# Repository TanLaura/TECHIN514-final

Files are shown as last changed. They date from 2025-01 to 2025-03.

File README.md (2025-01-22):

# TECHIN514-final

## Daily Habit Tracker
The device tracks the number of task completed (chips in the collector/sensing device) and show the progress with the stepper gauge needle. The LED light can be on the scale of red to green based on percentage of completion. It relies on the load cell and amplifier to calculate the number of chips of completed tasks and completion rate based on the set goal of the day. The stepper motor gauge and LED will display the progress. The display device also have the option to set the goals.

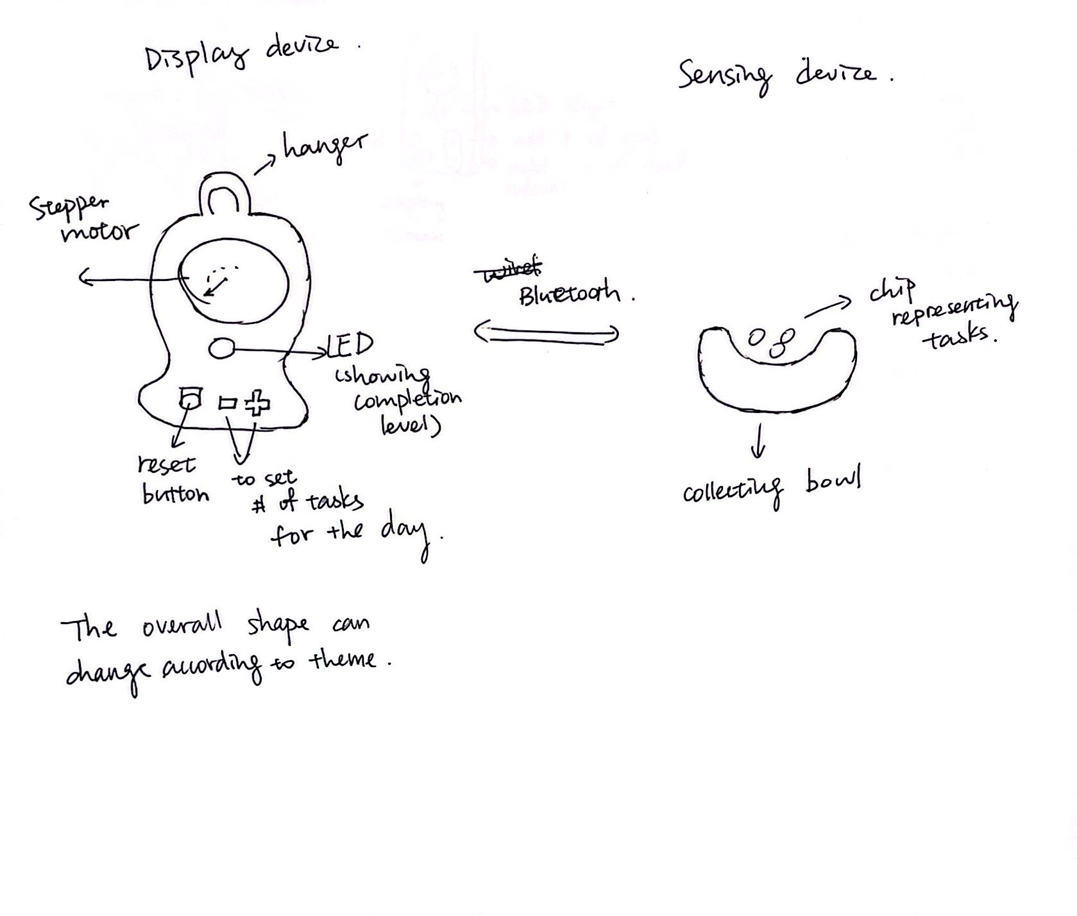
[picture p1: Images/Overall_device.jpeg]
Overview Graph


## Sensor device
The sensor device looks like a bowl overall. There is a load cell and amplifier that read the weight and translate it to voltage. It calculates the percentage of task completion and send the data to display device for further information display.
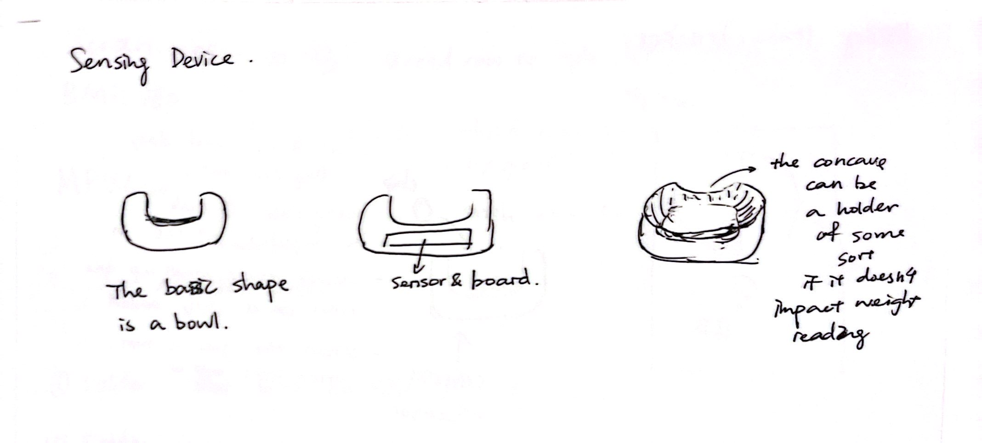
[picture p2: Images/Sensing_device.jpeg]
Sensing Device


## Display Device
The outer shape can be varied based on the final PCB shape and size. The diplay has a stepper motor gauge and LED light both shows the completion rate of the task in different forms. It has a reset button and button to adjust the goal of the day.
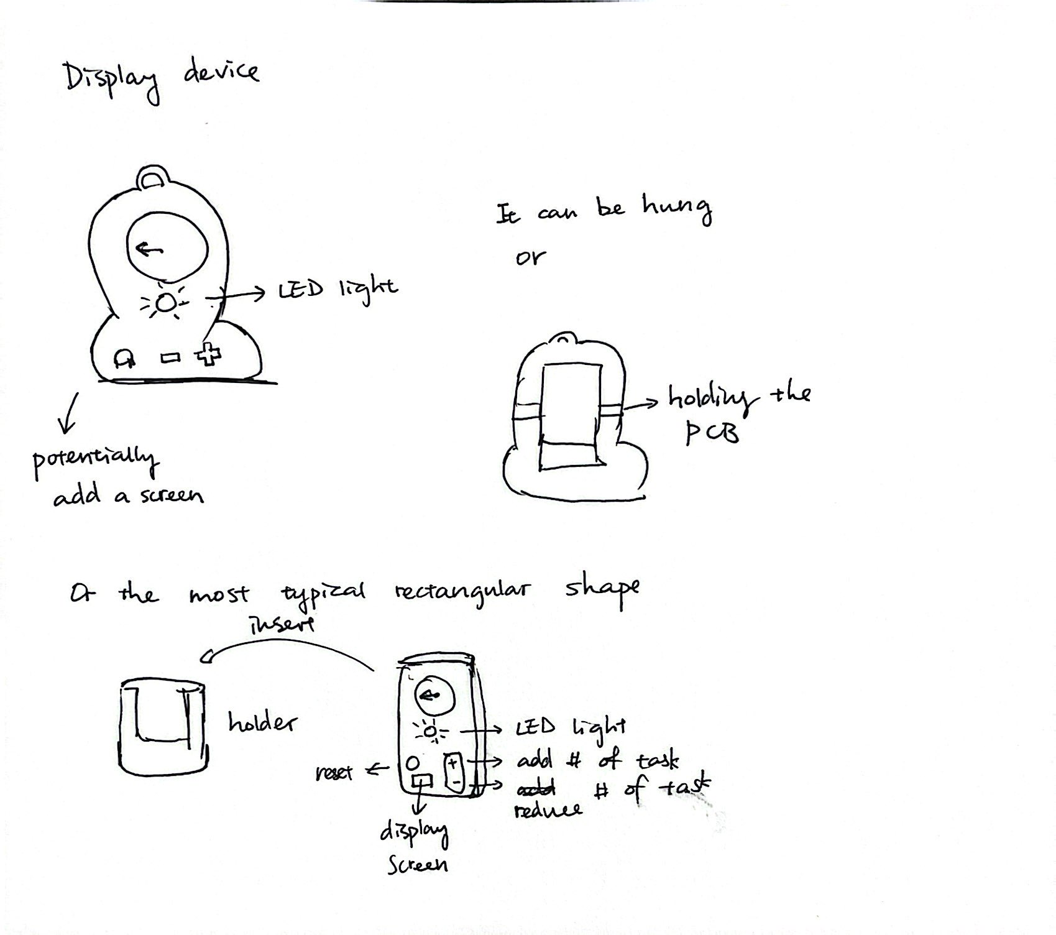
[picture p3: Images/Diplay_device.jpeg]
Display Device


## Device Communicatioin 

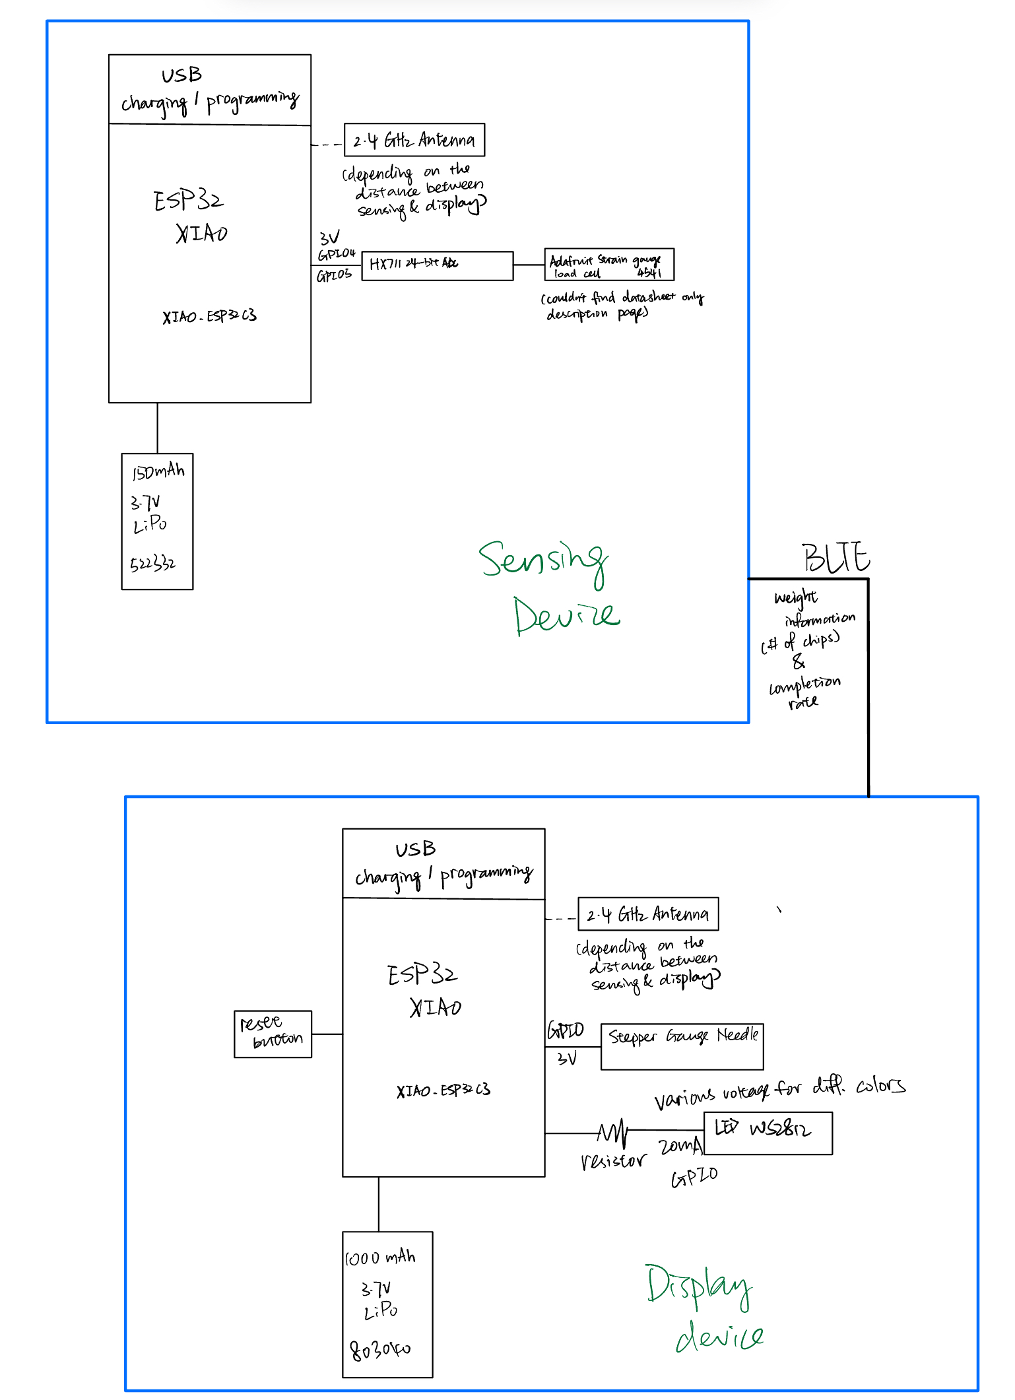
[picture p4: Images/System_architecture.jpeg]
System architecture


### Component Lists
- [Seeduino ESP32C3](Datasheets/Seeduino ESP32c3.pdf)
- [Load cell](https://www.adafruit.com/product/4541#description): The load cell seems to only have a webpage with product details instead of a datasheet.
- [HX711](Datasheets/adafruit-hx711-24-bit-adc.pdf)
- [Stepper Motor Gauage](Datasheets/stepd-01-data-sheet-1143075.pdf)
- [LED WS2812](Datasheets/WS2812.pdf)

### Potential Component to Add after Discussion 
- A small display screen
- The reset button (and its form)
- A charging circuit?
- Sleep mode?

These are all questions I want to go over with the instruction team to finalize the component list and structure.

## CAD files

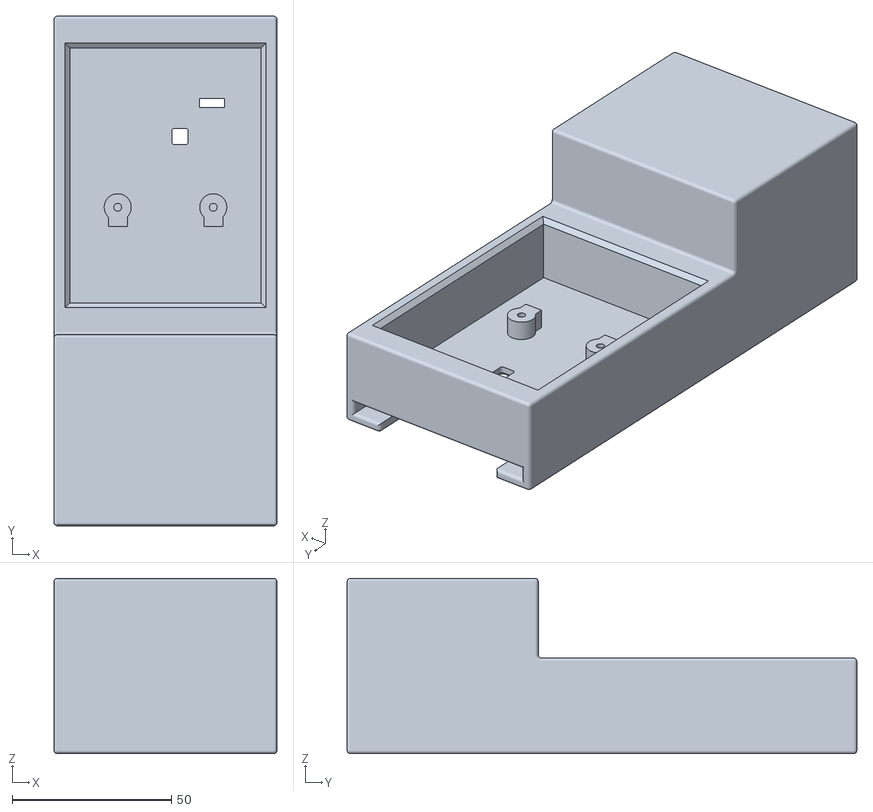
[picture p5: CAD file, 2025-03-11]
Enclosure/Sensor_Enclosure/Sensor_main.stl
70.0 x 160.0 x 55.0

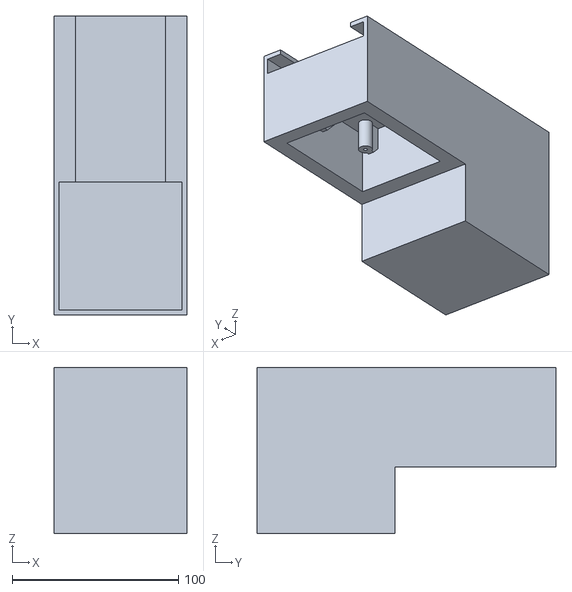
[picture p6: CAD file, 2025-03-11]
Enclosure/Sensor_Enclosure/Main body.stl
80.0 x 180.0 x 100.0

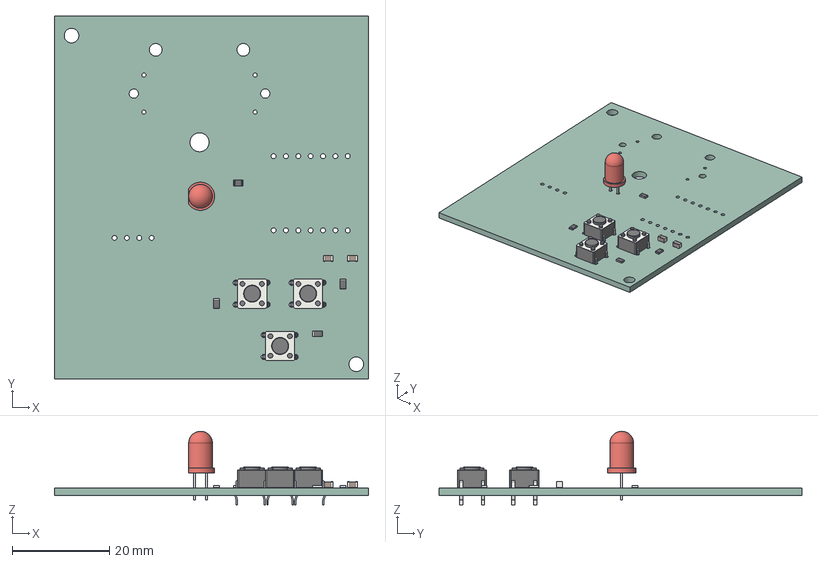
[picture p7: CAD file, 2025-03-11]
Enclosure/Display_Enclosure/514_final_display_pcb.step
64.5 x 74.5 x 15.1 mm
LED_D5.0mm
R_0805_2012Metric x 4
SW_PUSH_6mm x 3
C_0805_2012Metric x 2
514_final_display_pcb_PCB

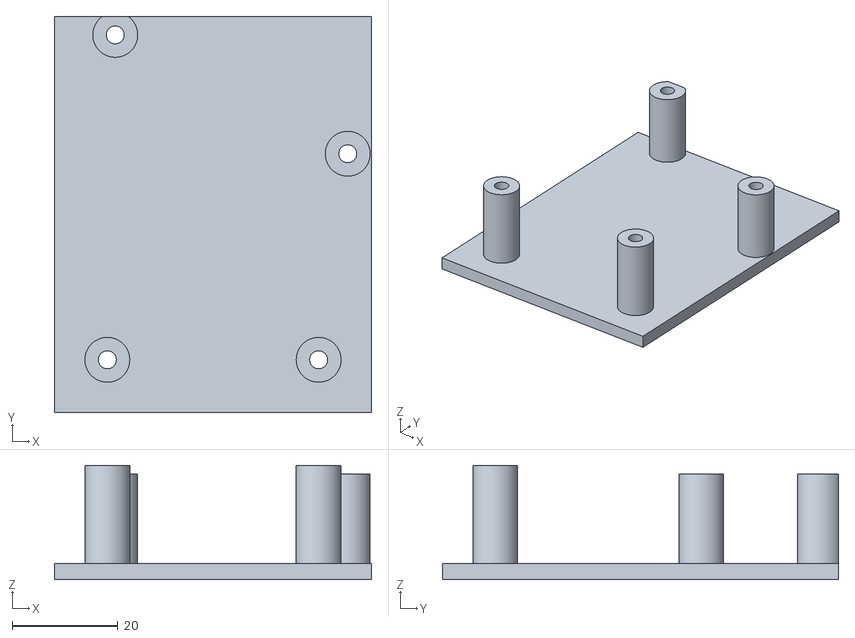
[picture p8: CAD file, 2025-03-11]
Enclosure/Sensor_Enclosure/Lid.stl
60.0 x 75.0 x 21.6

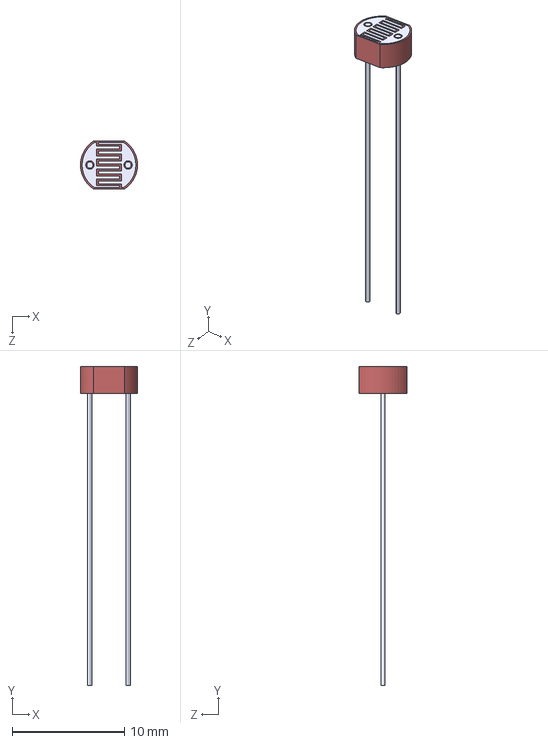
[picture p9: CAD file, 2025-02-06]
kiCAD resources/CDS_PDV_P8103/PDV-P8103.step
5.07 x 28.4 x 4.29 mm

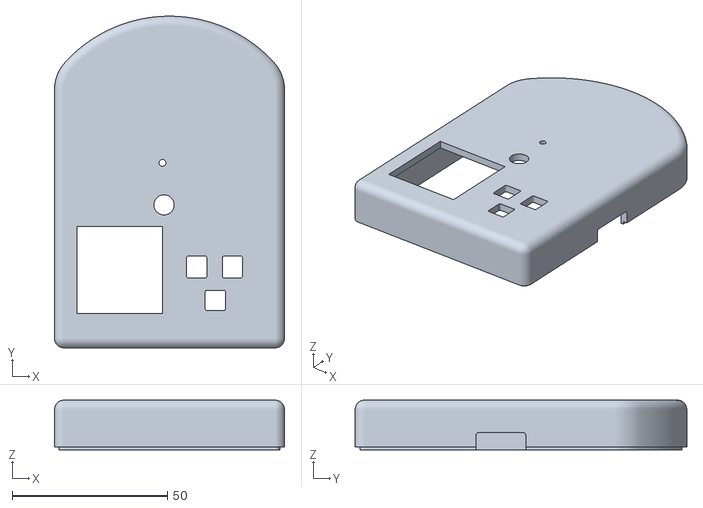
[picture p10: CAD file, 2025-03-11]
Enclosure/Display_Enclosure/Display_lid.stl
74.0 x 106.7 x 16.0

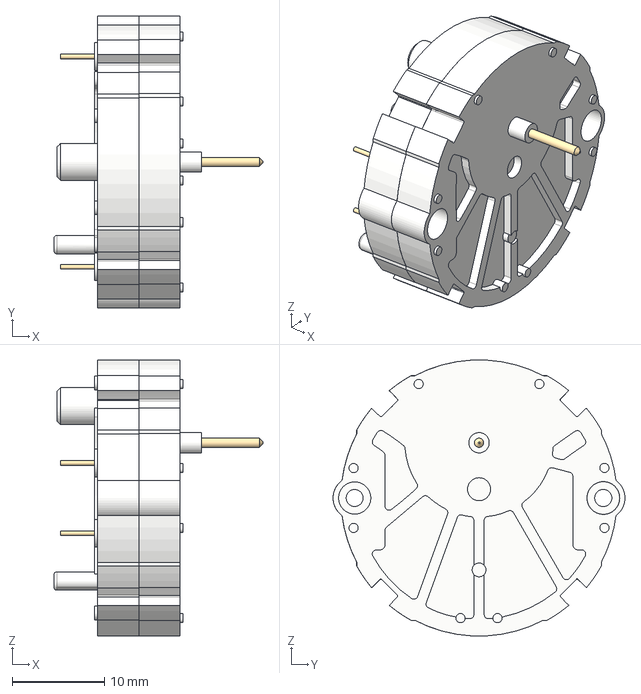
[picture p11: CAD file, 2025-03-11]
Enclosure/Display_Enclosure/X27-168-Stepper v5 (1).step
22.7 x 31.7 x 30.0 mm

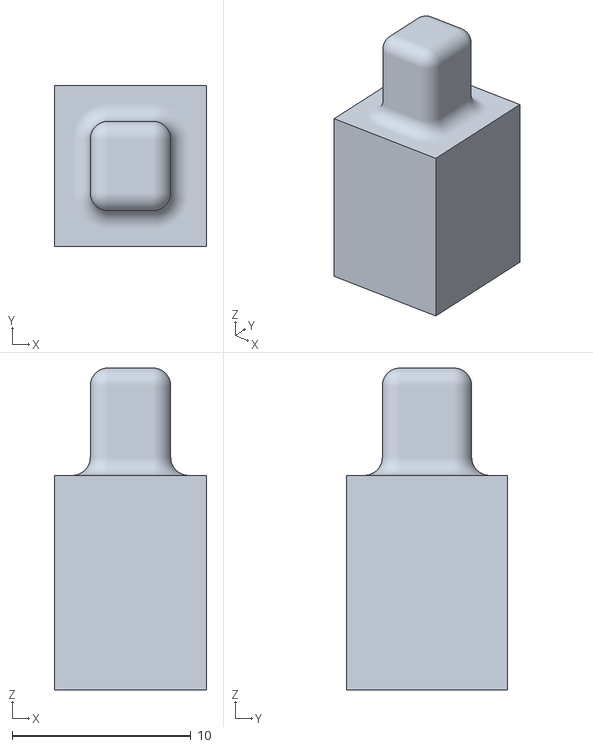
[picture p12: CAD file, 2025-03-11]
Enclosure/Display_Enclosure/button 2.stl
8.50 x 9.00 x 18.0

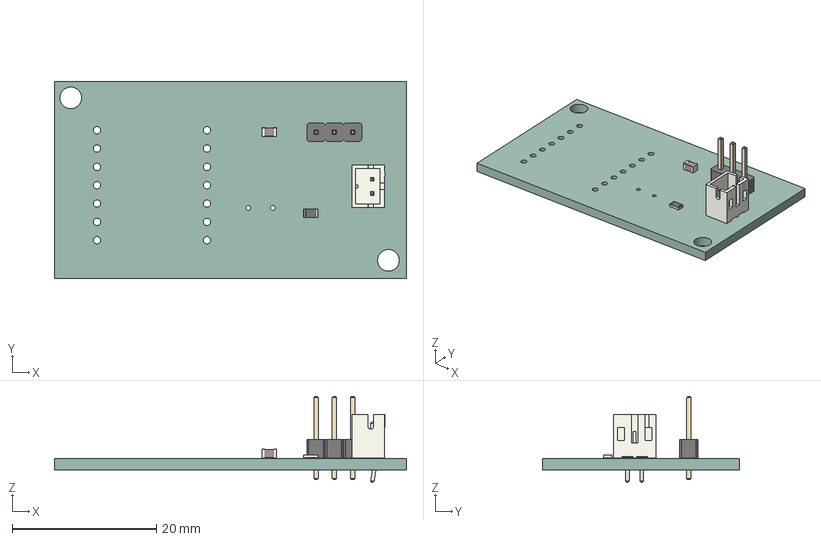
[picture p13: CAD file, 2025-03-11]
Enclosure/Sensor_Enclosure/514_final_sensor_pcb.step
48.8 x 27.2 x 11.9 mm
JST_B2B_PH_K
R_0805_2012Metric
C_0805_2012Metric
PinHeader_1x03_P254mm_Vertical
514_final_sensor_pcb_PCB

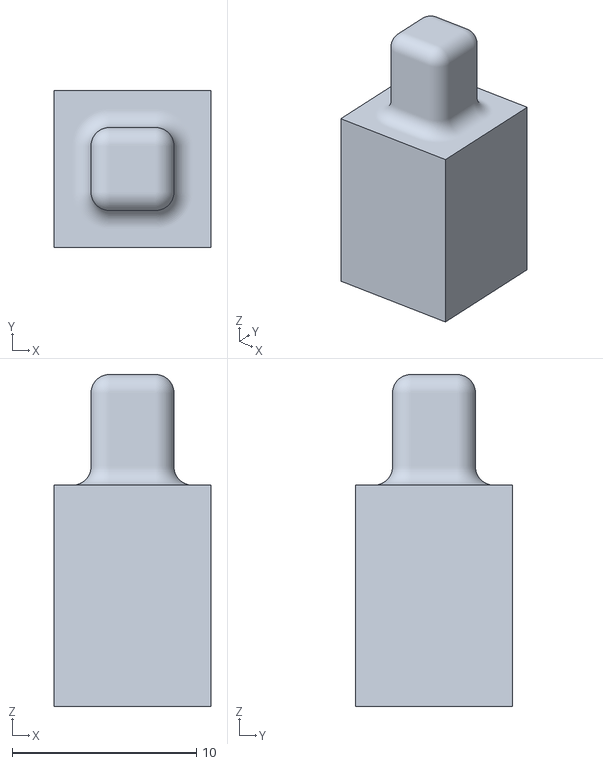
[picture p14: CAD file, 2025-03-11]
Enclosure/Display_Enclosure/button 3.stl
8.50 x 8.50 x 18.0

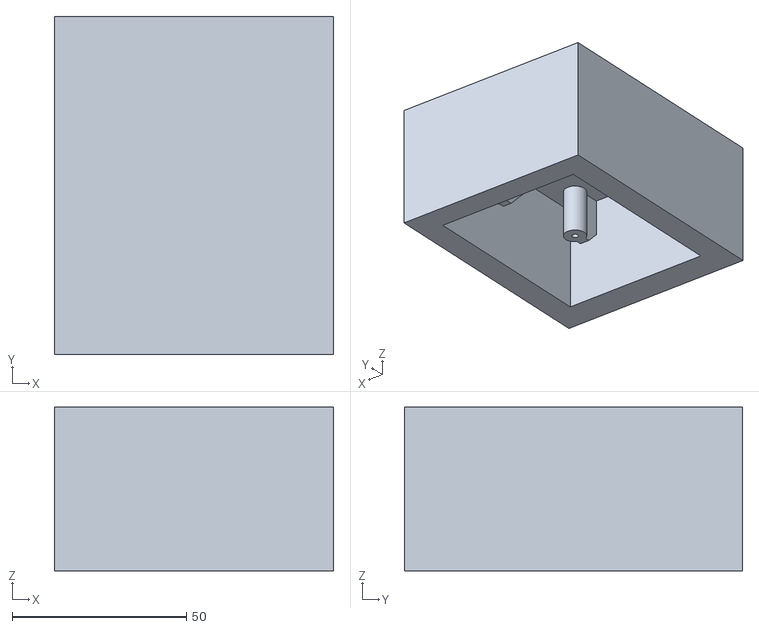
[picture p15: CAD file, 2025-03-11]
Enclosure/Sensor_Enclosure/PCB body.stl
80.0 x 97.0 x 47.0

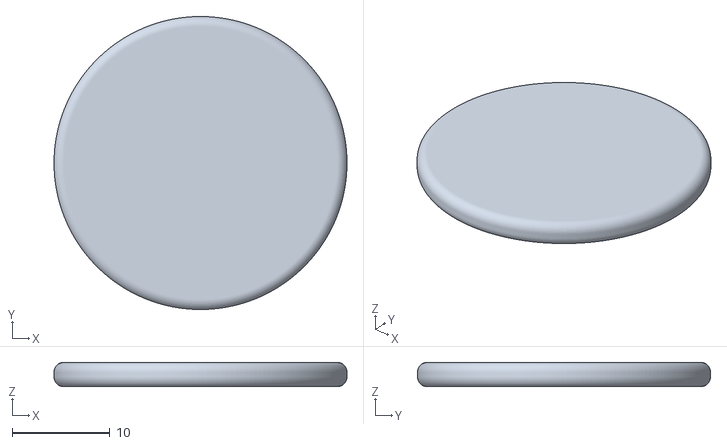
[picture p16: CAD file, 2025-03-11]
Enclosure/Display_Enclosure/Token.stl
30.0 x 30.0 x 2.50

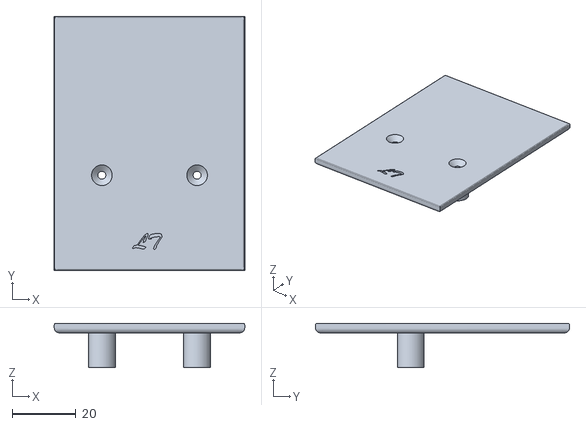
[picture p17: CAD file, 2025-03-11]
Enclosure/Sensor_Enclosure/sensor_lid.stl
60.0 x 80.0 x 14.0

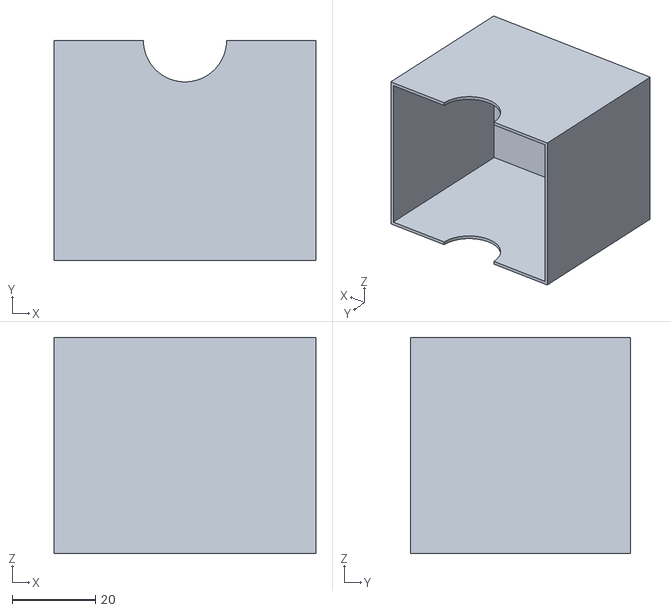
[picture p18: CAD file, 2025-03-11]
Enclosure/Sensor_Enclosure/sensor_drawer.stl
63.0 x 53.0 x 52.0

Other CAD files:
Enclosure/Display_Enclosure/Button.stl
Enclosure/Display_Enclosure/display_bottom.stl
Enclosure/Sensor_Enclosure/Sensor_enclosure v5.step
Enclosure/Sensor_Enclosure/Sensor_enclosure v5.f3d

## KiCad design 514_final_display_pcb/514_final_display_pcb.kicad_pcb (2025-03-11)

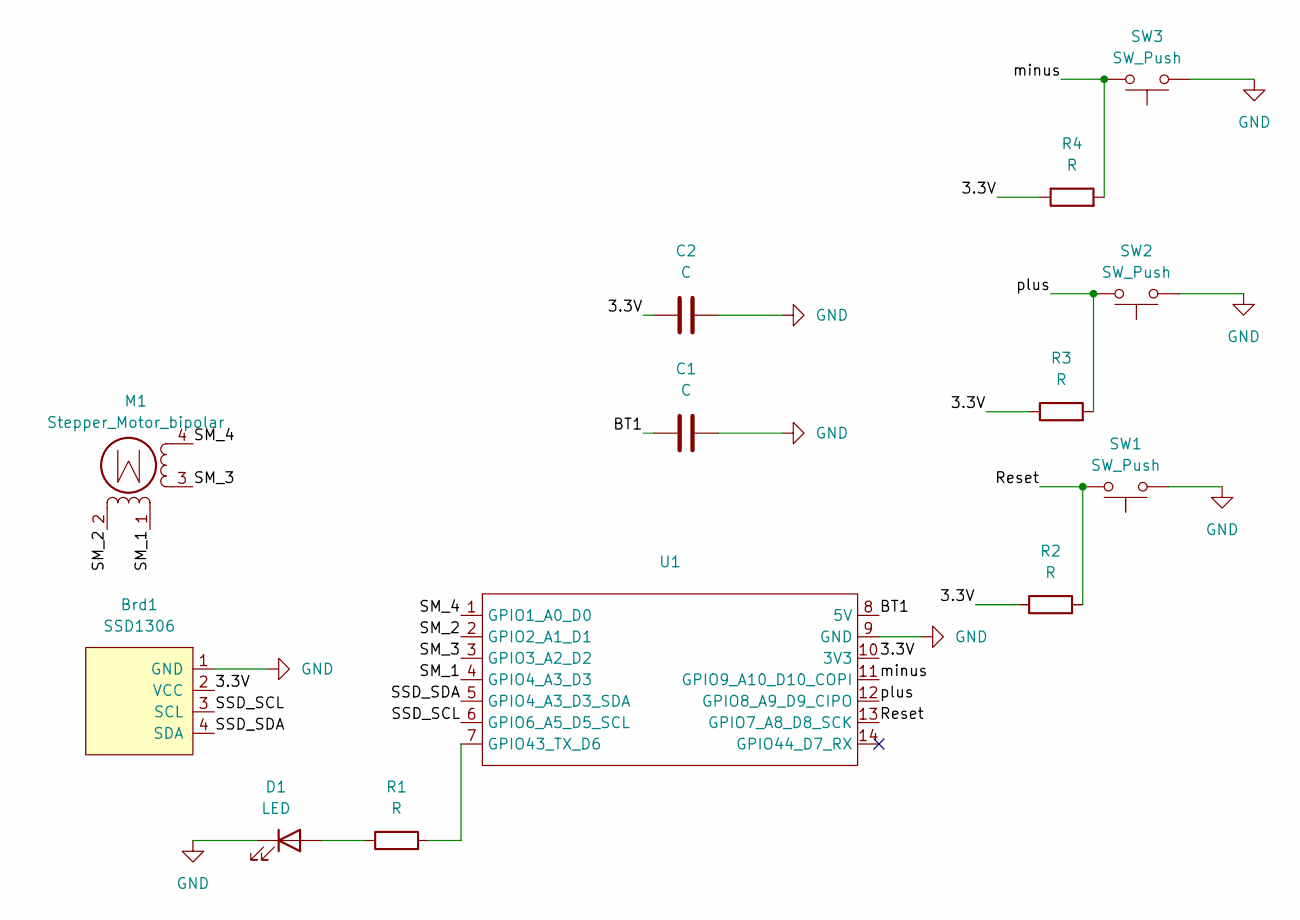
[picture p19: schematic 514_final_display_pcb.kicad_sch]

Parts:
Brd1: SSD1306; 128x64OLED
C1, C2: C; C_0805_2012Metric_Pad1.18x1.45mm_HandSolder
D1: LED; LED_D5.0mm
M1: Stepper_Motor_bipolar; x27_stepper_two_holes
R1, R2, R3, R4: R; R_0805_2012Metric_Pad1.20x1.40mm_HandSolder
SW1, SW2, SW3: SW_Push; SW_PUSH_6mm
U1: XIAO_ESP32_SENSE

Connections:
/3.3V: Brd1.2 (VCC), C2.1, R2.1, R3.1, R4.1, U1.10 (3V3)
/BT1: C1.1, U1.8 (5V)
/Reset: R2.2, SW1.2, U1.13 (GPIO7_A8_D8_SCK)
/SM_1: M1.1, U1.4 (GPIO4_A3_D3)
/SM_2: M1.2 (-), U1.2 (GPIO2_A1_D1)
/SM_3: M1.3, U1.3 (GPIO3_A2_D2)
/SM_4: M1.4, U1.1 (GPIO1_A0_D0)
/SSD_SCL: Brd1.3 (SCL), U1.6 (GPIO6_A5_D5_SCL)
/SSD_SDA: Brd1.4 (SDA), U1.5 (GPIO4_A3_D3_SDA)
/minus: R4.2, SW3.2, U1.11 (GPIO9_A10_D10_COPI)
/plus: R3.2, SW2.2, U1.12 (GPIO8_A9_D9_CIPO)
GND: Brd1.1 (GND), C1.2, C2.2, D1.1 (K), SW1.1, SW2.1, SW3.1, U1.9 (GND)
unnamed: D1.2 (A), R1.1
unnamed: R1.2, U1.7 (GPIO43_TX_D6)

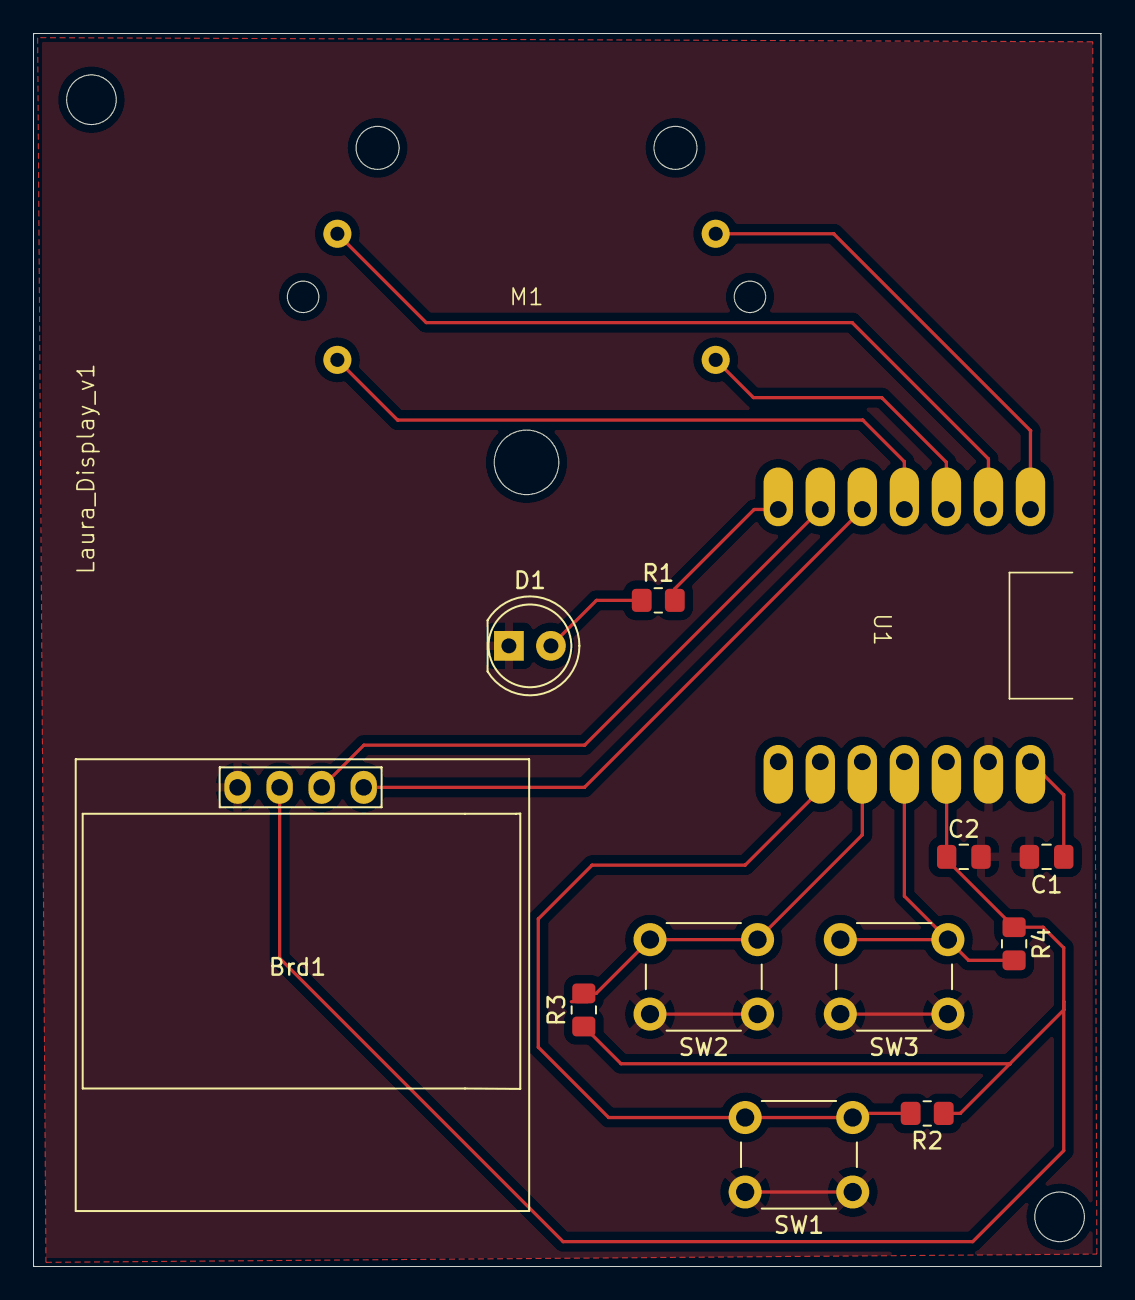
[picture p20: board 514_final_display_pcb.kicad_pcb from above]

Board: 2 copper layers, 64.5 x 74.5 mm, 13 parts (0 on the bottom side), 14 nets.

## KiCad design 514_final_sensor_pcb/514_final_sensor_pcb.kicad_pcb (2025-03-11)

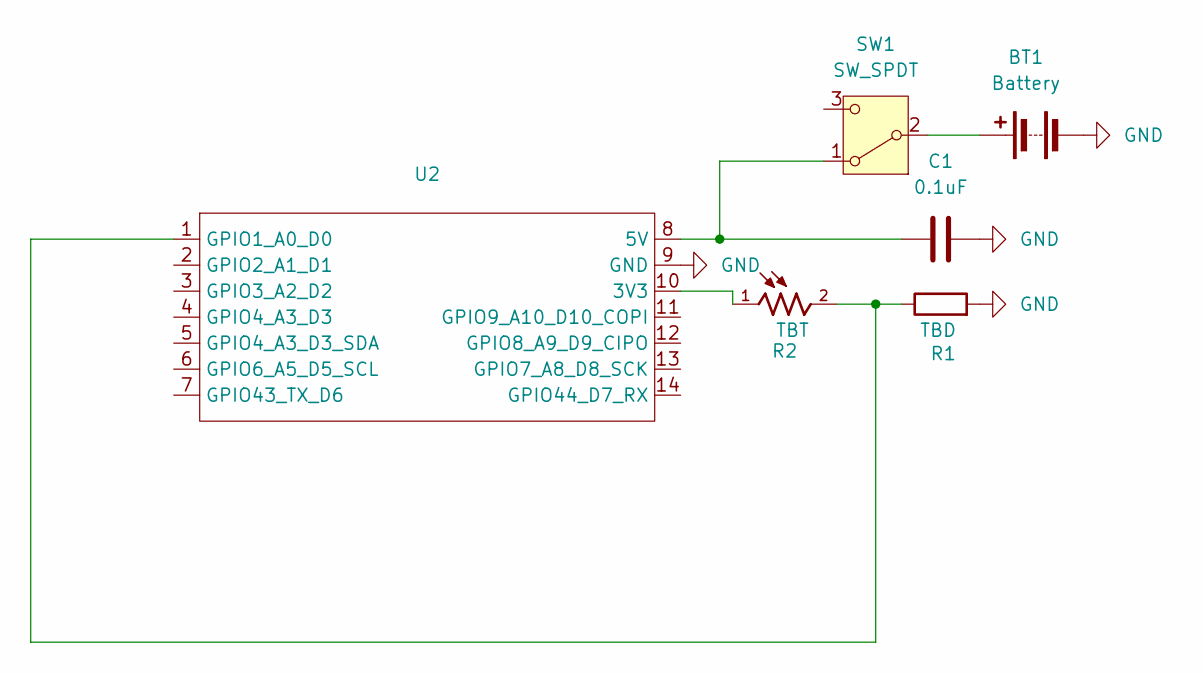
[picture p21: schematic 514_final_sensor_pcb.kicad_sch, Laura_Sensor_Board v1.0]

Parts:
BT1: Battery; JST_PH_B2B-PH-K_1x02_P2.00mm_Vertical
C1: 0.1uF; C_0805_2012Metric_Pad1.18x1.45mm_HandSolder
R1: TBD; R_0805_2012Metric_Pad1.20x1.40mm_HandSolder
R2: TBT; PHODET_PDV-P8103; PARTREV 3/30/06
SW1: SW_SPDT; PinHeader_1x03_P2.54mm_Vertical
U2: XIAO_ESP32_SENSE

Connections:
GND: BT1.2 (-), C1.2, R1.2, U2.9 (GND)
unnamed: BT1.1 (+), SW1.2 (B)
unnamed: C1.1, SW1.1 (A), U2.8 (5V)
unnamed: R2.1, U2.10 (3V3)
unnamed: R1.1, R2.2, U2.1 (GPIO1_A0_D0)

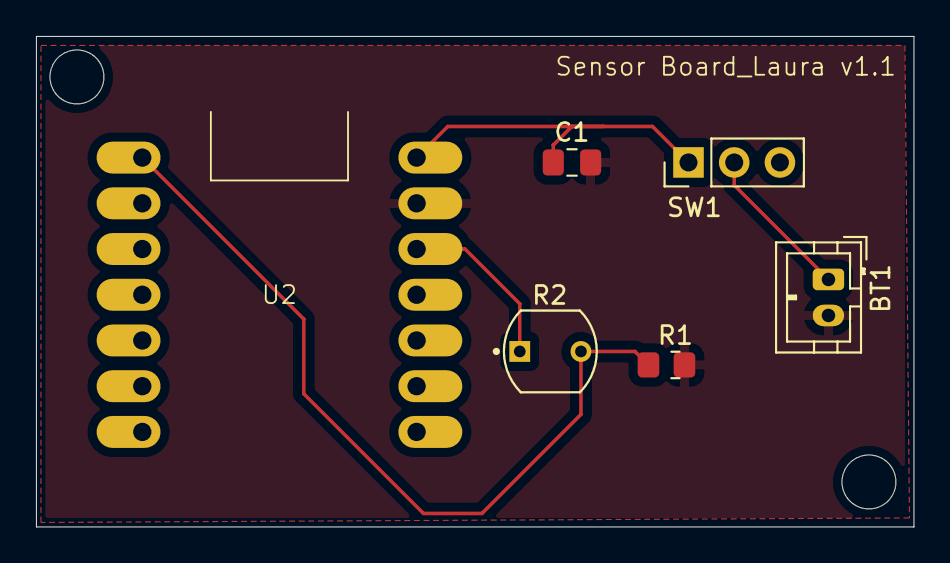
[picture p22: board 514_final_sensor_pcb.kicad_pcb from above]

Board: 2 copper layers, 48.8 x 27.2 mm, 6 parts (0 on the bottom side), 5 nets.

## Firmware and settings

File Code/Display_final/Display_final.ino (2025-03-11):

#include <Arduino.h>
#include <Wire.h>
#include <Adafruit_GFX.h>
#include <Adafruit_SSD1306.h>
#include <BLEDevice.h>
#include <BLEUtils.h>
#include <BLEScan.h>
#include <BLEAdvertisedDevice.h>

// Updated UUIDs
static BLEUUID serviceUUID("7fbc0737-9a04-4a22-83e0-f4a5da6ded0e");
static BLEUUID charUUID("ca15c078-2a49-4f56-9462-09a35021b10b");

// Button GPIOs
const int buttonPlus = 9;
const int buttonMinus = 10;
const int resetButton = 8;  // Reset button GPIO
const int ledPin = 21;
const int stepsPerRevolution = 600;

// Task and goal counters
int taskCount = 0;
int goalCount = 5;

// OLED display settings
#define COIL_A1 5  // Coil A+
#define COIL_A2 3  // Coil A-
#define COIL_B1 4  // Coil B+
#define COIL_B2 2  // Coil B-
#define SCREEN_WIDTH 128
#define SCREEN_HEIGHT 64
#define OLED_RESET -1  // No reset pin
Adafruit_SSD1306 display(SCREEN_WIDTH, SCREEN_HEIGHT, &Wire, OLED_RESET);

static boolean doConnect = false;
static boolean connected = false;
static boolean doScan = false;
static BLERemoteCharacteristic* pRemoteCharacteristic;
static BLEAdvertisedDevice* myDevice;

// Function Prototypes
void updateDisplay();
bool connectToServer();
void notifyCallback(BLERemoteCharacteristic* pBLERemoteCharacteristic, uint8_t* pData, size_t length, bool isNotify);

// BLE Client Connection Callback
class MyClientCallback : public BLEClientCallbacks {
  void onConnect(BLEClient* pclient) {
    Serial.println("Connected to BLE Server!");
    digitalWrite(ledPin, HIGH);  // Turn LED ON
  }

  void onDisconnect(BLEClient* pclient) {
    connected = false;
    Serial.println("Disconnected from BLE Server!");
    digitalWrite(ledPin, LOW);   // Turn LED OFF
  }
};

// BLE Scan Callback
class MyAdvertisedDeviceCallbacks: public BLEAdvertisedDeviceCallbacks {
  void onResult(BLEAdvertisedDevice advertisedDevice) {
    Serial.print("Found BLE device: ");
    if (advertisedDevice.haveName()) {
        Serial.println(advertisedDevice.getName().c_str());
    } else {
        Serial.println("Unnamed Device");
    }

    Serial.print("Device Address: ");
    Serial.println(advertisedDevice.getAddress().toString().c_str());

    if (advertisedDevice.haveServiceUUID() && advertisedDevice.isAdvertisingService(serviceUUID)) {
        Serial.println("Found HabitTracker_Sensor, connecting...");
        BLEDevice::getScan()->stop();
        myDevice = new BLEAdvertisedDevice(advertisedDevice);
        doConnect = true;
        doScan = true;
    }
  }
};

void setup() {
    Serial.begin(115200);
    Serial.println("Starting BLE client...");

    BLEDevice::init("HabitTracker_Display");

    pinMode(buttonPlus, INPUT_PULLUP);
    pinMode(buttonMinus, INPUT_PULLUP);
    pinMode(resetButton, INPUT_PULLUP);
    pinMode(ledPin, OUTPUT);
    digitalWrite(ledPin, LOW);

    // Initialize stepper motor pins
    pinMode(COIL_A1, OUTPUT);
    pinMode(COIL_A2, OUTPUT);
    pinMode(COIL_B1, OUTPUT);
    pinMode(COIL_B2, OUTPUT);

    if (!display.begin(SSD1306_SWITCHCAPVCC, 0x3C)) {
        Serial.println("⚠️ SSD1306 OLED initialization failed!");
        for (;;);
    }

    display.clearDisplay();
    display.setTextSize(1);
    display.setTextColor(WHITE);
    updateDisplay();

    BLEScan* pBLEScan = BLEDevice::getScan();
    pBLEScan->setAdvertisedDeviceCallbacks(new MyAdvertisedDeviceCallbacks());  
    pBLEScan->setInterval(1349);
    pBLEScan->setWindow(449);
    pBLEScan->setActiveScan(true);
    pBLEScan->start(5, false);
}

// **Function to step the X27 motor**
void stepMotor(int step) {
    switch (step % 4) {
        case 0:
            digitalWrite(COIL_A1, HIGH);
            digitalWrite(COIL_A2, LOW);
            digitalWrite(COIL_B1, HIGH);
            digitalWrite(COIL_B2, LOW);
            break;
        case 1:
            digitalWrite(COIL_A1, LOW);
            digitalWrite(COIL_A2, HIGH);
            digitalWrite(COIL_B1, HIGH);
            digitalWrite(COIL_B2, LOW);
            break;
        case 2:
            digitalWrite(COIL_A1, LOW);
            digitalWrite(COIL_A2, HIGH);
            digitalWrite(COIL_B1, LOW);
            digitalWrite(COIL_B2, HIGH);
            break;
        case 3:
            digitalWrite(COIL_A1, HIGH);
            digitalWrite(COIL_A2, LOW);
            digitalWrite(COIL_B1, LOW);
            digitalWrite(COIL_B2, HIGH);
            break;
    }
}

// **Function to move the X27 stepper motor back and forth three times**
void celebrateTaskCompletion() {
    Serial.println("🎉 Moving X27 stepper motor for celebration!");

    for (int j = 0; j < 3; j++) {  // Repeat movement 3 times
        Serial.print("🎉 Celebration Cycle: ");
        Serial.println(j + 1);

        // Move forward
        for (int i = 0; i < stepsPerRevolution / 4; i++) {
            stepMotor(i);
            delay(2);  // Adjust delay for speed
        }

        // Move backward
        for (int i = stepsPerRevolution / 4; i > 0; i--) {
            stepMotor(i);
            delay(2);
        }
    }

    Serial.println("🎉 Celebration movement complete!");
}

void loop() {
    if (doConnect) {
        if (connectToServer()) {
            Serial.println("Connected to BLE server.");
        } else {
            Serial.println("Failed to connect to server.");
        }
        doConnect = false;
    }

    if (!connected && doScan) {
        BLEDevice::getScan()->start(0);
    }

    // Handle goal setting buttons
    if (digitalRead(buttonPlus) == LOW) {
        goalCount++;
        Serial.print("Goal increased! New goal: ");
        Serial.println(goalCount);
        updateDisplay();
        delay(300);
    }

    if (digitalRead(buttonMinus) == LOW) {
        if (goalCount > 0) {
            goalCount--;
            Serial.print("Goal decreased! New goal: ");
            Serial.println(goalCount);
            updateDisplay();
        } else {
            Serial.println("Goal cannot be negative!");
        }
        delay(300);
    }

    // **Reset button handling**
    if (digitalRead(resetButton) == LOW) {
        Serial.println("🔄 Reset button pressed! Resetting counters...");
        taskCount = 0;
        goalCount = 5;  // Default goal count
        updateDisplay();
        delay(500);  // Debounce delay
    }

    delay(100);
}

// **Display Update Function**
void updateDisplay() {
    display.clearDisplay();
    
    // Show taskCount/goalCount on the first line
    display.setCursor(10, 10);
    display.print("Tasks: ");
    display.print(taskCount);
    display.print("/");
    display.print(goalCount);

    // Calculate and display completion rate
    float completionRate = (goalCount > 0) ? ((float)taskCount / goalCount) * 100 : 0;
    
    display.setCursor(10, 30);  // Move to the next line
    display.print("Completion: ");
    display.print((int)completionRate);  // Convert to int for clean display
    display.print("%");

    display.display();
}

// **BLE Notification Callback**
void notifyCallback(
  BLERemoteCharacteristic* pBLERemoteCharacteristic,
  uint8_t* pData,
  size_t length,
  bool isNotify) {

    Serial.print("Received BLE Notification: ");
    int receivedValue = pData[0];
    Serial.print("Token Detection Value: ");
    Serial.println(receivedValue);

    if (receivedValue == 1) {
        taskCount++;
        Serial.print("✅ Task completed! Total tasks completed: ");
        Serial.println(taskCount);
        updateDisplay();

        // **Trigger Stepper Celebration**
        celebrateTaskCompletion();
    } else {
        Serial.println("⚠️ Unexpected value received.");
    }
}

// **BLE Server Connection**
bool connectToServer() {
    Serial.print("Connecting to BLE Server at ");
    Serial.println(myDevice->getAddress().toString().c_str());

    BLEClient* pClient = BLEDevice::createClient();
    Serial.println(" - Created BLE client");

    pClient->setClientCallbacks(new MyClientCallback());

    if (pClient->connect(myDevice)) {
        Serial.println(" - Successfully connected to BLE server!");

        if (myDevice->haveName()) {
            Serial.print(" - Connected to server name: ");
            Serial.println(myDevice->getName().c_str());
        } else {
            Serial.println(" - Connected to unnamed BLE server.");
        }

        pClient->setMTU(517);

        BLERemoteService* pRemoteService = pClient->getService(serviceUUID);
        if (pRemoteService == nullptr) {
            Serial.println("Failed to find service UUID");
            pClient->disconnect();
            return false;
        }
        Serial.println(" - Found service");

        pRemoteCharacteristic = pRemoteService->getCharacteristic(charUUID);
        if (pRemoteCharacteristic == nullptr) {
            Serial.println("Failed to find characteristic UUID");
            pClient->disconnect();
            return false;
        }
        Serial.println(" - Found characteristic");

        if (pRemoteCharacteristic->canNotify()) {
            pRemoteCharacteristic->registerForNotify(notifyCallback);
        }

        connected = true;
        return true;
    } else {
        Serial.println(" - Failed to connect to BLE server.");
        return false;
    }
}

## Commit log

2025-01-29 updated datasheet & partial schematic
    [514_final_display_pcb.kicad_pcb, 514_final_display_pcb.kicad_sch, 514_final_sensor_pcb.kicad_pcb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]
2025-02-06 sensor pcb v1.0
    [514_final_sensor_pcb.kicad_pcb, PDV-P8103.step]
2025-02-14 battery estimate and datasheet update
    [514_final_sensor_pcb-B_Cu.gbr, 514_final_sensor_pcb-B_Mask.gbr, 514_final_sensor_pcb-B_Paste.gbr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]
2025-02-14 spreadsheet update
    [Simple_ Power Model for TECHIN514.xlsx]
2025-03-11 second device
    [514_final_display_pcb-B_Cu.gbr, 514_final_display_pcb-B_Mask.gbr, 514_final_display_pcb-B_Paste.gbr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]
